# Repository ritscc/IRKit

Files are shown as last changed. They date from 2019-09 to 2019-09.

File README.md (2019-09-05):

# IRKit
KC3 2019 RCC勉強会
IRKit 基板設計データ
# Dependency
[KiCAD](http://kicad-pcb.org)

## FootPrint
- [ZX62-B-PA(33)](https://www.snapeda.com/parts/ZX62-B-5PA%2833%29/Hirose%20Electric%20Co%20Ltd/view-part/)
- [BS170](https://www.snapeda.com/parts/BS170/ON%20Semiconductor/view-part/)
- [kc3_logo](KiCad/lib/kc3-logo/kc3_logo.pretty)
- [AKI-PARTS](KiCad/lib/AKI-PARTS.pretty)

# Setup
1. `git clone git@github.com:ritscc/IRKit.git`
1. Log in [snapeda](https://www.snapeda.com/account/login/)
1. Download & unzip [ZX62-B-PA(33)](https://www.snapeda.com/parts/ZX62-B-5PA%2833%29/Hirose%20Electric%20Co%20Ltd/view-part/), [BS170](https://www.snapeda.com/parts/BS170/ON%20Semiconductor/view-part/) FootPront to IRKit project directory `./IRKit/`

# License
This software is released under the MIT License, see LICENSE.

# Authors
RCC
- aonori@[aonrjp](https://aonr.jp)
- nekopanda@[hirotta3a](https://twitter.com/hirotta3a)

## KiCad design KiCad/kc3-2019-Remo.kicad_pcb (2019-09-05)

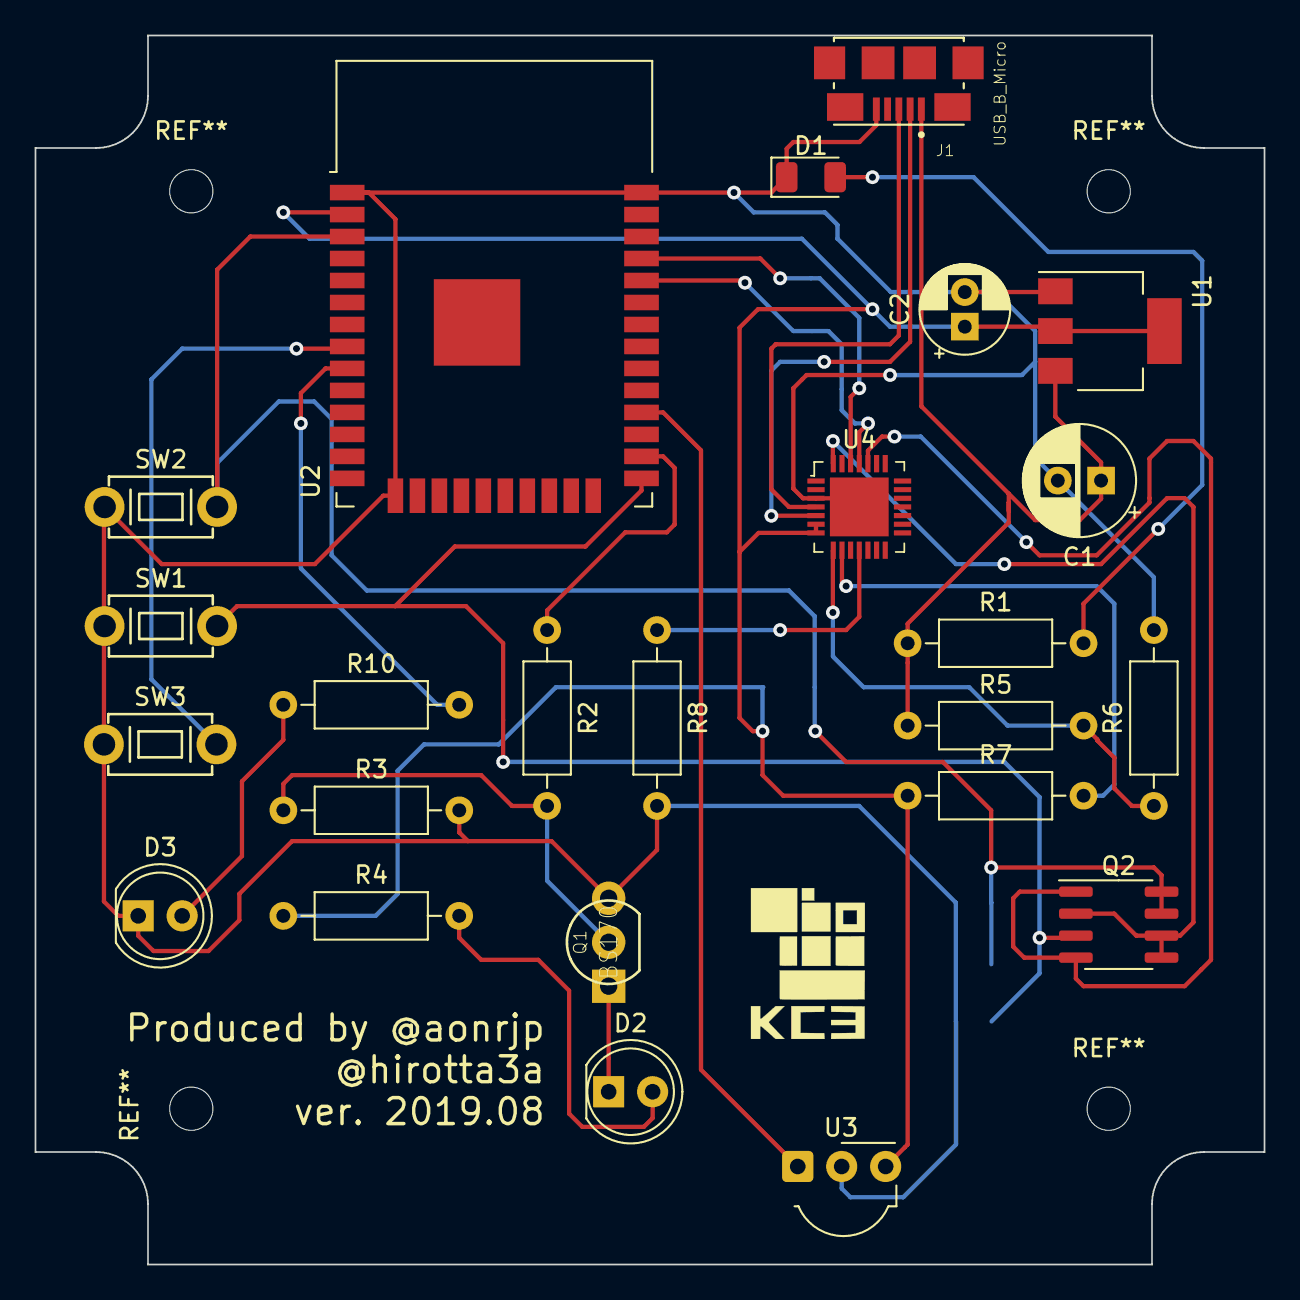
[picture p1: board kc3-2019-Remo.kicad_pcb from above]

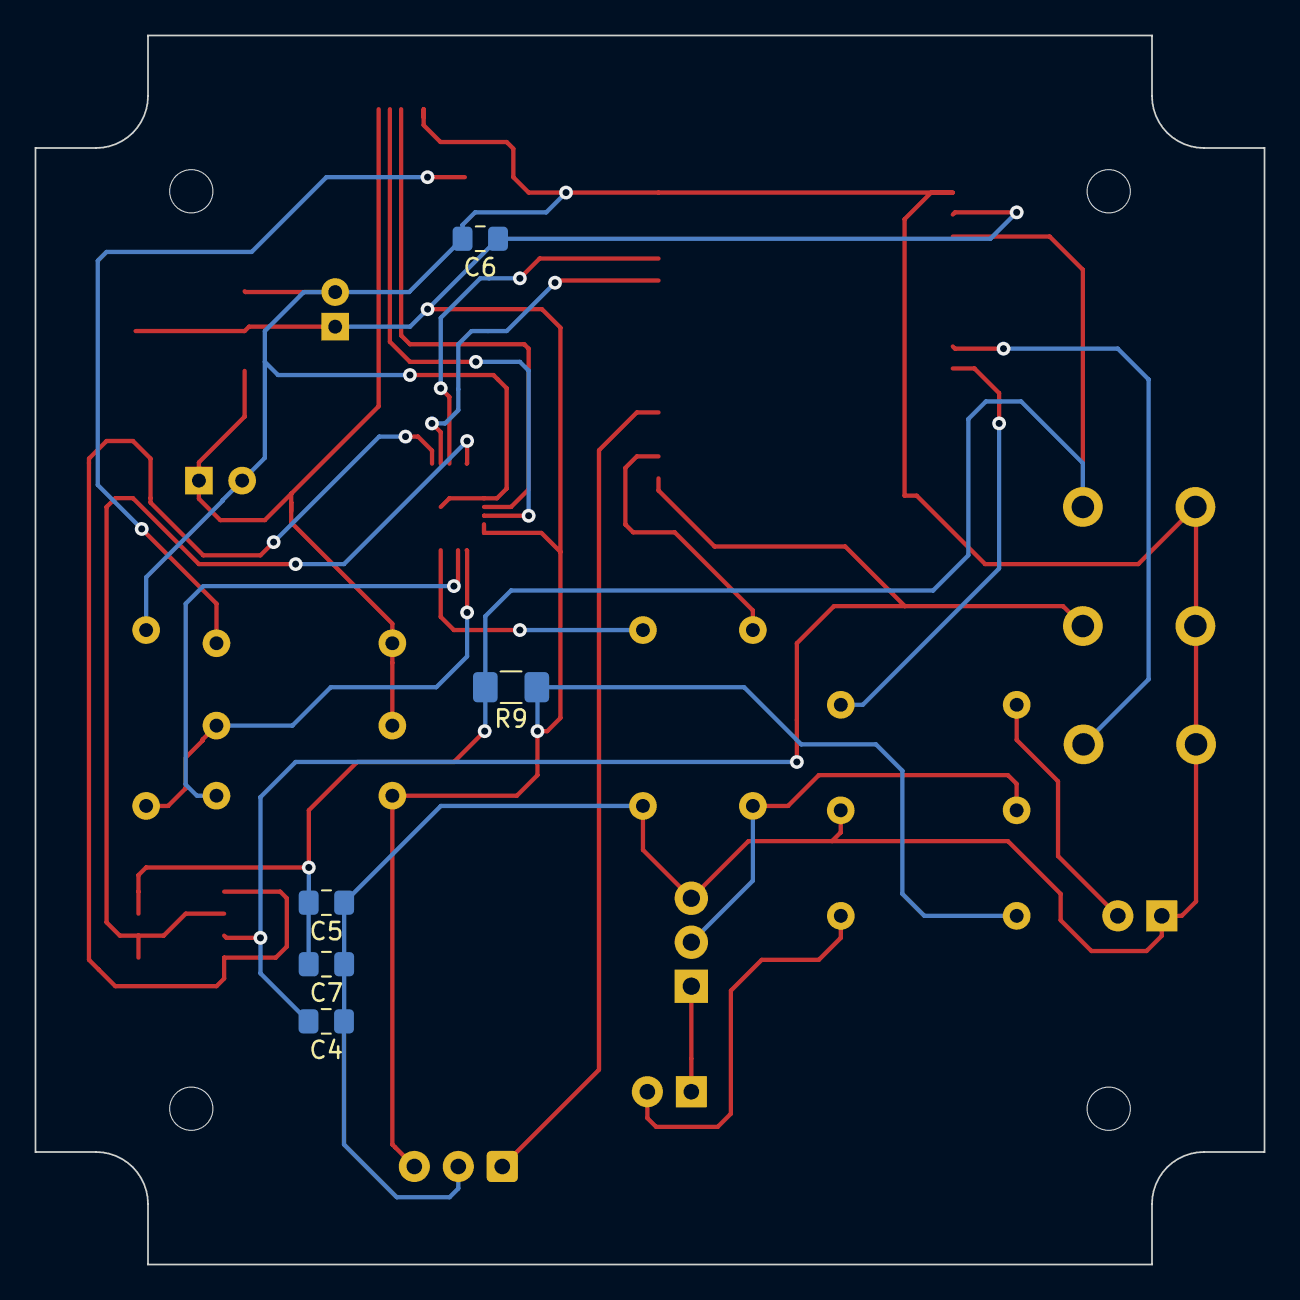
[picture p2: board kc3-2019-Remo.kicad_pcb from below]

Board: 2 copper layers, 71.0 x 71.0 mm, 29 parts (5 on the bottom side), 23 nets.

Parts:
C1: 47u; CP_Radial_D6.3mm_P2.50mm
C2: 22u; CP_Radial_D5.0mm_P2.00mm
C4, C5, C6, C7: 0.1u; C_0805_2012Metric_Pad1.15x1.40mm_HandSolder
D1: LED; LED_1206_3216Metric
D2: OSI5FU5111C-40; LED_D5.0mm
D3: GREEN_LED; LED_D5.0mm
J1: USB_B_Micro; HRS_ZX62-B-5PA(33)
Q1: BS170; TO92
Q2: NDS9936; SOIC-8_3.9x4.9mm_P1.27mm
R1: 2k; R_Axial_DIN0207_L6.3mm_D2.5mm_P10.16mm_Horizontal
R2, R10: 22; R_Axial_DIN0207_L6.3mm_D2.5mm_P10.16mm_Horizontal
R3, R8: 10k; R_Axial_DIN0207_L6.3mm_D2.5mm_P10.16mm_Horizontal
R4: 1; R_Axial_DIN0207_L6.3mm_D2.5mm_P10.16mm_Horizontal
R5: 24k; R_Axial_DIN0207_L6.3mm_D2.5mm_P10.16mm_Horizontal
R6: 47k; R_Axial_DIN0207_L6.3mm_D2.5mm_P10.16mm_Horizontal
R7: 4.7k; R_Axial_DIN0207_L6.3mm_D2.5mm_P10.16mm_Horizontal
R9: 10k; R_1206_3216Metric_Pad1.42x1.75mm_HandSolder
SW1: FLASH_SW; TVBP06-B043CX-B
SW2: RST_SW; TVBP06-B043CX-B
SW3: USER_SW; TVBP06-B043CX-B
U1: AMS1117-3.3; SOT-223-3_TabPin2
U2: ESP32-WROOM-32
U3: OSRB38C9AA; Vishay_MOLD-3Pin
U4: CP2102-GMR_NRND; VFQFN-28-1EP_5x5mm

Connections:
+3V3: C2.1, C6.1, R4.1, R7.1, R9.1, U1.2, U2.2, U3.3, U4.6, U4.7
+5V: C1.1, J1.1, R1.1, R5.1, U1.3
DTR: Q2.2, Q2.5, Q2.6, U4.28
EN: C5.2, C7.2, Q2.7, Q2.8, R9.2, SW2.1, U2.3
GND: C1.2, C2.2, C4.1, C5.1, C6.2, C7.1, D1.1, D3.1, J1.5, Q1.3, R3.2, R6.2, R8.2, SW1.2, SW2.2, SW3.2, U1.1, U2.1, U2.15, U2.38, U3.2, U4.3, U4.29
IO0: C4.2, Q2.3, SW1.1, U2.25
IR_LED: R2.1, U2.26
IR_REC: U2.28, U3.1
unnamed: D1.2, R1.2
unnamed: D2.1, Q1.1
unnamed: D2.2, R4.2
unnamed: D3.2, R10.1
unnamed: Q1.2, R2.2, R3.1
unnamed: R5.2, R6.1, U4.8
unnamed: R7.2, U4.9
unnamed: R8.1, U4.11
unnamed: R10.2, U2.9
unnamed: SW3.1, U2.8
RTS: Q2.1, Q2.4, U4.24
RXD0: U2.34, U4.25
TXD0: U2.35, U4.26
USB_DN: J1.2, U4.5
USB_DP: J1.3, U4.4

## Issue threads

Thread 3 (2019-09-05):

[TASK] 基板テスト用プログラム作成

greenlaver, 2019-09-05:
## 背景
基板実装が終わった時点で、テスト用プログラムを実行し、基板が正しく実装されているかを確認したい。

## 実装要件
- [ ] テスト用LEDのLチカ
- [ ] SerialのRX/TX動作確認
- [ ] 赤外線LEDの動作確認
- [ ] 赤外線フォトトランジスタの動作確認
- [ ] その他ハードウェア的な確認項目の洗い出し

## 説明
上記項目について、動作が確認できさえすればよい。初回の検品のみに利用するプログラムなので、操作性よりも**実装時間の短さ**と**動作確実**かが重視。
理想的には、基板への部品実装者が最終工程においてスムーズに検品できるよう、手順書を含め整備すべきかね...

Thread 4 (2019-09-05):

[TASK] 赤外線リモコンの学習

greenlaver, 2019-09-05:
## 背景
スマートリモコンを作成するためには、既存のリモコンを学習する必要がある。
ライブラリはある程度揃っているので、まずはそれらを利用して、講座で使用可能な状態（質問されても答えられる程度に理解すべき）に持っていく必要がある。

### ref
- [IRremoteESP32](https://github.com/luclala/IRremoteESP32)

## 実装要件
- [ ] hoge

## 説明

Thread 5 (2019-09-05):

[TASK] 赤外線LEDの駆動

greenlaver, 2019-09-05:
## 背景
リモコンとして動作するために、高出力で適切なパルスを駆動する必要がある。ただのLチカとは違い、タイマ割り込みなりで適切に捌く必要がありそう。

## 実装要件
- [ ] タイマ割り込み等でほぼ正確にシグナルを出力するシステム
- [ ] 搬送波に乗せてデータを飛ばすシステム

## 注意点
回路設計はパルス発信を前提としているため、1回の点灯は**10ms以下**にする必要がある。長時間点灯の場合は、あらかじめ**R4**を適切な抵抗値に変更すること。

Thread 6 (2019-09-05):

[TASK] ネットワークからのリクエストを受ける

greenlaver, 2019-09-05:
## 背景
IoTとしてのスマートリモコンを製作しているので、WANからのリクエストを受けてリモコンとして動作する必要がある。

## 実装要件
- [ ] 記録済みのリモコン発信を発火するメソッドないしエンドポイント
- [ ] WANからのリクエストを安全に受ける何かしらの機構
  - IFTTTとかになりそう

## 説明
LANで終わってしまうとIoTにする意味がないので、そこんとこよろしく。

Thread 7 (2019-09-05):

[TASK] 台風をどうにかする

greenlaver, 2019-09-05:
## 背景
**台風15号**が迫っている

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

## 実装要件
- [ ] 台風をどうにかする

## 説明
KC3直撃、やめてください。

itanium-R, 2019-09-06:
無理難題で草

もしも本当に
ＫＣ３参加者の
安心安全を
考えるならば
わたくしも暴風での休講大好きですけども、
法律で台風の来日を
禁止して、
禁止すればいい（

itanium-R, 2019-09-06:
よく学校である告知はいるよなぁ

暴風警報または気象等に関する特別警報が発令された場合もしくは気象等により交通機関が不通となった場合の本イベントの取り扱いは、下表の通りとします。
1 暴風警報または気象等に関する特別警報が午前７時００分の時点で京都府、大阪府、奈良県、滋賀県の１地域以上に発令されている場合、${中止か延期}とする。
2  JR 西日本(神戸―草津間、京都―二条間)、阪急(梅田―河原町間)、京阪、近鉄の 4 交通機関のうち、3 交通機関以上が不通の場合、${中止か延期}とする。

↑こんな感じ

greenlaver, 2019-09-07:
普通にまともなコメントを頂けて感謝（さーせんw）

Closed 2019-09-07.

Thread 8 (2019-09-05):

[TASK] 講義資料作成

greenlaver, 2019-09-05:
## 背景
勉強会そのものに対して、当日用意すべき資料を列挙して、準備に役立てる。

## 実装要件
- [ ] IoT、スマートデバイスについての概略的な説明スライド
- [ ] リモコンそのものの仕組み
- [ ] ワークショップの作業手順解説資料
  - 部品表、回路図、簡単な組み立て手順はpdfか紙を手元に配布すべき

## 説明
その他必要なものあれば随時コメントで議論 → 要件に追加

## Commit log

2019-09-05 Move KiCad project files into 'KiCad' dir.
    [kc3-2019-Remo.sch]
2019-09-05 add kicad pcb file
    [kc3-2019-Remo.kicad_pcb]
